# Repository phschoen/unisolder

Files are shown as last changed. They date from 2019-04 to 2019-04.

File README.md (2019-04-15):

# unisolder

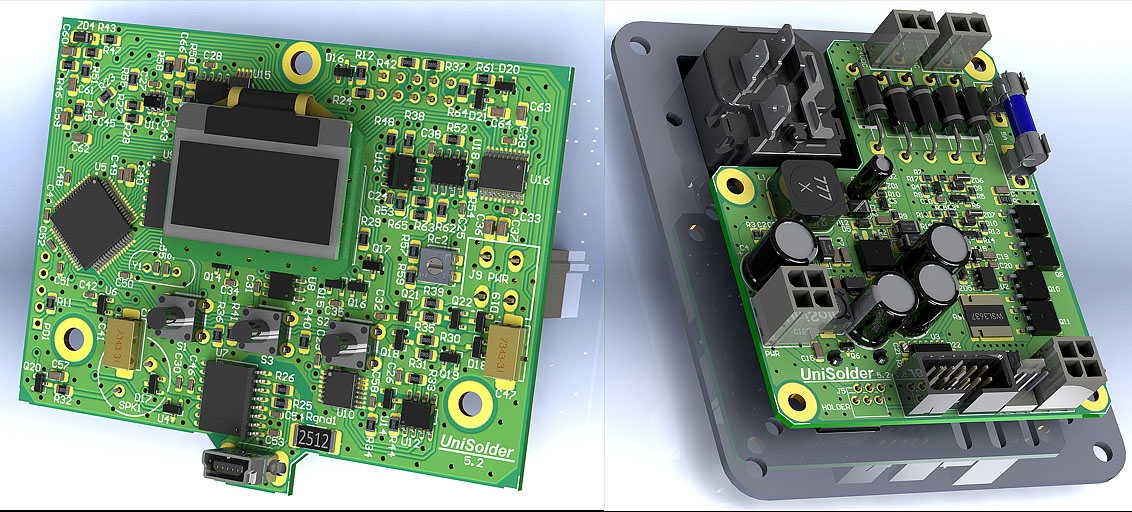
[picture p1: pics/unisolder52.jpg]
unisolder52


The intention was to build the most universal soldering controller I can think of.
It can drive any low voltage (upto 24V) iron with thermocouple or resistive sensor,
in series with the heater, or separate.

Here is a short list of features:
- power: 9-28V, AC or DC
- 2 separate heater control channels
- 2 independent sensor inputs
- current source on any sensor input 3uA - 12mA, wuth 2 bands (x1, x16) and 256 steps per band
- flexible differential amplifier input selection
- amplifier gain from 0 to 750 in 256 steps
- negative offset selection in 1024 steps
- resistive instrument identification (upto 625 different instruments can be identified by 2 resistors on the connector)
- polynomial floating point voltage/resistance to temperature calculation
- wave shaping to filter out the inductive peaks from series sensor signal
- PID control with power limit
- isolated USB port for firmware updates and live data
- 128x64 OLED display with rich user interface.

Tested so far with:
- HAKKO T12/T15 (series TC)
- HAKKO FX8801 (PTC)
- PACE TD100 (series TC)
- JBC C245 (series or separate TC)
- JBC C210 (series TC)
- JBC Microtweezers (2 separate heaters, each with series TC)
- WELLER WSP80 (PTC) (This iron was sent to me by a reader of the thread for a previous version of the controller. Thanks, Jaroslaw)
- ERSA RT80 (series PTC/heater resistance)
- various chinese cheap irons with separate TC

## Update (4 April 2017): 
The PC Software is now entirely in C#, the front end is rewritten. Now you can program only the bootloader,
and then use the software for firmware updates using the USB connection. The PC software also does not crash
anymore when device is unplugged and plugged in the USB or turned on/off, and automatically switches to
bootloader and back when uploading new firmware. Also, a legend with checkboxes is added for every data
that is displayed on the graph, so you can switch it on or off. There is still pretty much work to be done on it,
but at least it is much more functional now.
Added to the firmware are Pace TD100 Black and Weller WMRT profiles, some work is done on several other places.
Now the firmware handles better some irons, where there was initial overshoot when heating for the first time
or changing the target temperature.

Some movies:
 - [JBC C245](https://www.youtube.com/watch?v=oTdQB4ywDOA)
 - [JBC C210](https://www.youtube.com/watch?v=iyz-EDf-JaY)
 - [T12, JBC C210, JBC Microtweezers](https://www.youtube.com/watch?v=-f0KSU0PJzc&t=70s)
 - [Chinese T12](https://www.youtube.com/watch?v=u588sh-4thg)
 - [Weller WSP80](https://www.youtube.com/watch?v=gd_8w7l8_Bo)
 - [Weller WMRT](https://www.youtube.com/watch?v=eHNJuQEw6XU)

The content of this is originaly copied thanks to sparkybg from [dangerousprototypes.com](http://dangerousprototypes.com/forum/viewtopic.php?t=7218)

## Connections to different tips/irons:

1. HAKKO T12:
- Outer shell, and heater negative (middle) terminal connected together to Vout1- and EARTH
- heater positive (bottom terminal) connected to Vout1+ and SENSEA
- 1k resistor between ID and Vout1-
- 5.6k resistor between ID and Vout2-

2. HAKKO FX8801, HAKKO 907 (original, with PTC sensor):
- Outer shell, PTC negative and heater negative connected to EARTH, Vout1- and SENSEB
- Heater positive connected to Vout1+
- PTC positive connected to SENSEA
- 1k between ID and Vout1-
- 820ohm between ID and Vout2-

3. JBC C245:
- Outer shell (green wire) connected to EARTH and SENSEB
- Heater positive(red wire) connected to Vout1- and SENSEA
- Heater negative(blue wire) connected to Vout1+
- 150ohm between ID and Vout1-
- 5.6k between ID and Vout2-

4. JBC C210:
- Outer shell (green wire) connected to EARTH and SENSEB
- Heater negative (middle terminal, blue wire) connected to Vout1-
- Heater positive (smaller terminal, red wire) connected to Vout1+ and SENSEA
- 3.0k between ID and Vout1-
- 5.6k between ID and Vout2-

5. JBC Microtweezers:
- Outer shell of both tips (green wire) connected to EARTH
- Heater 1 negative (blue wire) connected to Vout1-
- Heater 1 positive (red wire) connected to Vout1+ and SENSEA
- Heater 2 negative (brown wire) connected to Vout2-
- Heater 2 positive (yellow wire) connected to Vout2+ and SENSEB
- 1.0k between ID and Vout1-

6. WELLER WSP80:
- Outer shell, PTC negative and heater negative (white, black and brown wires) connected to EARTH, Vout1- and SENSEB
- Heater positive (blue wire) connected to Vout1+
- PTC positive (red wire) connected to SENSEA
- 120ohm between ID and Vout1-
- 5.6k between ID and Vout2-

7. ERSA RT80:
- Outer shell and Heater/PTC negative (pink and white wires) connected to EARTH, Vout1- and SENSEB
- Heater/PTC positive (black wire) connected to Vout1+ and SENSEA
- 300ohm between ID and Vout1-
- 110ohm between ID and Vout2-

see also https://github.com/5N44P/unisolder-notes

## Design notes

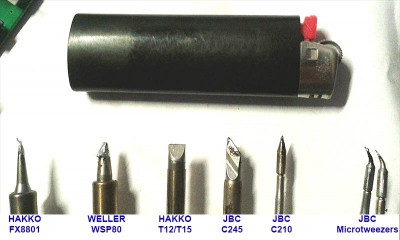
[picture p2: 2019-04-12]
pics/iron_tips.jpg

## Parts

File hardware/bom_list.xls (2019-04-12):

Designator | Comment | Supplier | Quantity | Package | Description
C1, C3, C5, C7, C9, C10, C17, C18, C59, C60, C62, C65 | 10n 100V | Comet | 12 | 0805 | Capacitor
C2, C6, C12, C16, C20, C21, C67, C70, C73, C74, C77 | 100n 100V | Comet | 11 | 0805 | Capacitor, Capacitor, Capacitor, Capacitor, Capacitor, Capacitor, Capacitor (Semiconductor SIM Model), Capacitor, Capacitor, Capacitor, Capacitor
C4 | 470uF 16V | Comet | 1 | TH10x12.5 | Polarized Capacitor (Radial)
C8, C11 | 220uF 50V | Comet | 2 | TH10x12.5 | Polarized Capacitor (Radial)
C13 | 22uF 50V | Comet | 1 | TH5x11 | Polarized Capacitor (Radial)
C14, C15, C19 | 10u 25V | Comet | 3 | 1206 | Capacitor
C22 | 47uF 100V | Comet | 1 | TH10x12.5 | Polarized Capacitor (Radial)
C23, C47 | 220uf 10V | Comet | 2 | D | Tantalum SMD Capacitor
C24, C25, C26, C27, C28, C29, C30, C31, C32, C33, C34, C35, C38, C39, C41, C42, C43, C44, C45, C46, C48, C49, C50, C51, C52, C53, C54, C58 | 100n | Comet | 28 | 0603 | Capacitor
C36, C37, C40, C57, C68, C69, C75 | 10u 16V | Comet | 7 | 0805 | Capacitor
C55, C56 | 15p | Comet | 2 | 0603 | Capacitor
C61, C63, C64, C66 | 1n | Comet | 4 | 0805 | Capacitor
C71 | 10u 25V | Comet | 1 | 0805 | Capacitor
C76 | 100p | Comet | 1 | 0805 | Capacitor
D1, D2, D3, D4 | SR580 | Comet | 4 | DO-201AD | Schottky Diode
D5, D8, D10, D14, D15 | BAT46WH | Comet | 5 | SOD123 | Schottky Rectifier
D6, D7, D12 | SS310A | Comet | 3 | SMA | Schottky Rectifier
D9, D11, D13 | 1N4007 | Comet | 3 | SMA | 1 Amp General Purpose Rectifier
D16, D17, D20, D21 | BAV199 | Farnell | 4 | SOT23
D18, D19 | MMBD1505A | Farnell | 2 | SOT23
D22 | SS34A | Comet | 1 | SMA | Schottky Rectifier
DS1, DS2, DS3 | SA36-11SRWA | Comet | 3 | DIP10 | 7.62 mm Black Surface HER 7-Segment Display: CA, RH DP
FUSE1 | 5A | Comet | 1 | 2x3518P | 2x Keystone 3518P fuse holder
J1 | 24VAC | Comet | 1 | 1x2x4.2 | Header, 2-Pin
J2 | IRON | Comet | 1 | 2x2x4.2 | Header, 4-Pin
J3, J9 | PWR | Comet | 2 | 2x2x4.2 | Header, 4-Pin
J4, J8 | CNTR | Comet | 2 | 2x5x2.54 | Header, 10-Pin
J5 | HOLDER | Comet | 1 | RJ11V | Header, 8-Pin
J6 | SENSOR | Comet | 1 | CI31-3 | Header, 3-Pin
J7 | 24VDC | Comet | 1 | 1x2x4.2 | Header, 2-Pin
Ja, Jb, Jc, Jd, Je, Jg | 0 | Comet | 6 | 0403 | Resistor
L1 | 330uH | Comet | 1 | DRH125 | Inductor
L2 | 330uH | Comet | 1 | DRH74 | Inductor
L3 | 10uH | Farnell | 1 | LPS4018 | Inductor
OLED1 | UG-2864HSWEG01 | Texim | 1 |  | 0.96' 128x64 OLED Display
P1, P2, PD1 | Header 5 | Comet | 3 | 1x5x2.54 | Header, 5-Pin
Q1 | FZT605 | Comet | 1 | SOT89 | SOT223 NPN Silicon Planar Medium Power Darlington Transistor
Q2, Q8 | SUD50P10 | Farnell | 2 | TO252 | HEXFET Power MOSFET
Q3, Q9 | MMBT5401 | Comet | 2 | SOT23 | PNP General-purpose Transistor
Q4, Q5, Q12 | MMBT5551 | Comet | 3 | SOT23 | NPN General-purpose Transistor
Q6, Q13 | BC847C | Comet | 2 | SOT23 | NPN General-purpose Transistor
Q7 | BCX56-16 | Comet | 1 | SOT89 | NPN High-voltage Transistor
Q10, Q11 | IPD053N08 | Farnell | 2 | TO252 | HEXFET N-Channel Power MOSFET
Q14, Q15, Q16, Q18, Q19, Q21, Q22 | IRLML6401 | Comet | 7 | SOT23 | HEXFET Power MOSFET
Q17, Q20 | IRLML2502 | Comet | 2 | SOT23 | HEXFET Power MOSFET
R1 | 10k | Comet | 1 | 1206 | Resistor
R2, R7, R15, R19, R21, R22 | 4.7k | Comet | 7 | 0805 | Resistor
R3 | 0 | Comet | 7 | 0805 | Resistor/Solder jumper
R4, R30, R35, R37, R42, R52, R54, R55, R56, R57, R59, R62, R65 | 1.5k 0.1% | Farnell, Farnell, Farnell, Farnell, Farnell, Farnell, Farnell, Comet, Farnell, Farnell, Farnell, Farnell, Farnell | 13 | 0805 | Resistor
R5, R11, R12, R13, R16, R17, R36, R40, R41, R45, R46, R58, R68, R69 | 3k | Comet | 14 | 0805 | Resistor
R6, R9, R14 | 150 | Comet | 3 | 0805 | Resistor
R8, R18 | 30k | Comet | 2 | 0805 | Resistor
R10 | 10k | Farnell | 1 | 0805 | Resistor
R20, R32 | 330 | Comet | 2 | 0805 | Resistor
R23, R27, R28, R33, R44 | 1.8k | Comet | 5 | 0805 | Resistor
R24, R34, R51, R60 | 1k 0.1% | Farnell | 4 | 0805 | Resistor
R25, R26 | 27 | Comet | 2 | 0805 | Resistor
R29, Ra, Rb, Rc, Rd, Re, Rf, Rg | 47 | Comet | 8 | 0805 | Resistor
R31, R39 | 100 0.1% | Farnell | 2 | 0805 | Resistor
R38, R48 | 47k 0.1% | Farnell | 2 | 0805 | Resistor
R43, R61, R64 | 15k | Comet | 3 | 0805 | Resistor
R47, R49, R50, R66 | 27k 0.1% | Farnell | 4 | 0805 | Resistor
R53, R63 | 10k 0.1% | Farnell | 2 | 0805 | Resistor
R67 | 820k | Comet | 1 | 0805 | Resistor
Rc2 | 2k | Farnell | 1 | Bourns 3362 | Potentiometer
Rgnd1 | 10000k | Comet | 1 | 2512 | Resistor
Rs1 | 0.003 | Comet | 1 | WSL3637 | 4lead shunt resistor
S1, S2, S3 | SWITCH-TACTILE | Comet | 3
SPK1 | PB1221P | Comet | 1 | SPK12x9x6.5 | Speaker 12mm
TVS1 | 60V | Farnell | 1 | DO-201AD | Tranzorb
U1 | LM2675M-3.3 | Comet | 1 | SOIC8 | SIMPLE SWITCHER® Power Converter High Efficiency 1A Step-Down Voltage Regulator, 8-pin Narrow SOIC
U2 | TC4428ACOA | Comet | 1 | SOIC8 | 1.5A Dual High-Speed Power MOSFET Driver, Complementary, Commercial Temperature
U3 | SN74HC02D | Comet | 1 | SOIC14 | Quadruple 2-Input Positive-NOR Gate
U4 | TC1047AVNBTR | Comet | 1 | SOT23 | Precision Temperature-to-Voltage Converter, 3-Pin SOT-23, Extended Temperature, Tape and Reel
U5 | PIC32MX564F128H-I/PT | Farnell | 1 | TQFP64 | High Performance 80 MHz MIPS-Based 32-Bit Flash Microcontroller with USB and CAN, 128KB Program Memory, 64-pin TQFP, Industrial Temperature
U6 | REF3030 | Farnell | 1 | SOT23
U7 | ADuM3160 | Farnell | 1 | SOIC16W | USB Isolator
U8 | 24LC64-I/SN | Comet | 1 | SOIC8 | 64Kbit, 400kHz, 2.5V, I2C Serial EEPROM, 8-Pin SOIC 150mil, Industrial Temperature
U9 | ULN2003L | Comet | 1 | SOIC16 | High-Voltage, High-Current Darlington Array
U10 | MCP4651-503E/ST | Farnell | 1 | TSSOP14 | 8-Bit Dual I2C Digital POT with Volatile Memory, 14-pin TSSOP, Extended Temperature
U11 | MCP4716A0T-E/CH | Farnell | 1 | SOT23-6 | 10-Bit Voltage Output Digital-to-Analog Converter with EEPROM and I2C Interface, 6-Pin SOT-23, Extended Temperature, Tape and Reel
U12, U13, U18 | MCP6V27-E/SN | Farnell | 3 | SOIC8 | 110 µA, High Precision Dual Op Amp, 8-Pin SOIC, Extended Temperature, 620 µA, 2 MHz Auto-Zeroed Dual Op Amp, 8-Pin SOIC, Extended Temperature, 620 µA, 2 MHz Auto-Zeroed Dual Op Amp, 8-Pin SOIC, Extended Temperature
U14 | LM4041CIM3-1.2 | Farnell | 1 | SOT23 | Precision Micropower Shunt Voltage Reference, 3-pin SOT-23
U15 | MCP4561T-503E/MS | Farnell | 1 | MSOP8 | 8-Bit Single I2C Digital POT with Non-Volatile Memory, 8-pin MSOP, Extended Temperature, Tape and Reel
U16 | ADG734 | Farnell | 1 | TSSOP20 | AD 4 SPDT
U17 | MCP6V28-E/SN | Farnell | 1 | SOIC8 | 620 µA, 2 MHz Auto-Zeroed Op Amp with CS pin, 8-Pin SOIC, Extended Temperature
U19 | FAN5331 | Comet | 1 | SOT23-5 | LED boost driver
USB1 | USB 5 pin | Comet | 1 | MINIUSB-V
Y1 | 8Mhz | Comet | 1 | HC49US | Crystal Oscillator
ZD1, ZD2 | 3V | Comet | 2 | SOD123 | Zener Diode
ZD3 | 36V | Comet | 1 | SOD123 | Zener Diode
ZD4 | 3.0V | Comet | 1 | SOD123 | Zener Diode
ZD5, ZD6, ZD7 | 15V | Comet | 3 | SOD123 | Zener Diode

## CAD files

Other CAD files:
software/front/US_BootLoader.X/l.obj
software/front/US_Firmware.X/l.obj
software/sensor/US_sensor.X/dist/default/production/US_sensor.X.production.obj
software/sensor/US_sensor.X/l.obj

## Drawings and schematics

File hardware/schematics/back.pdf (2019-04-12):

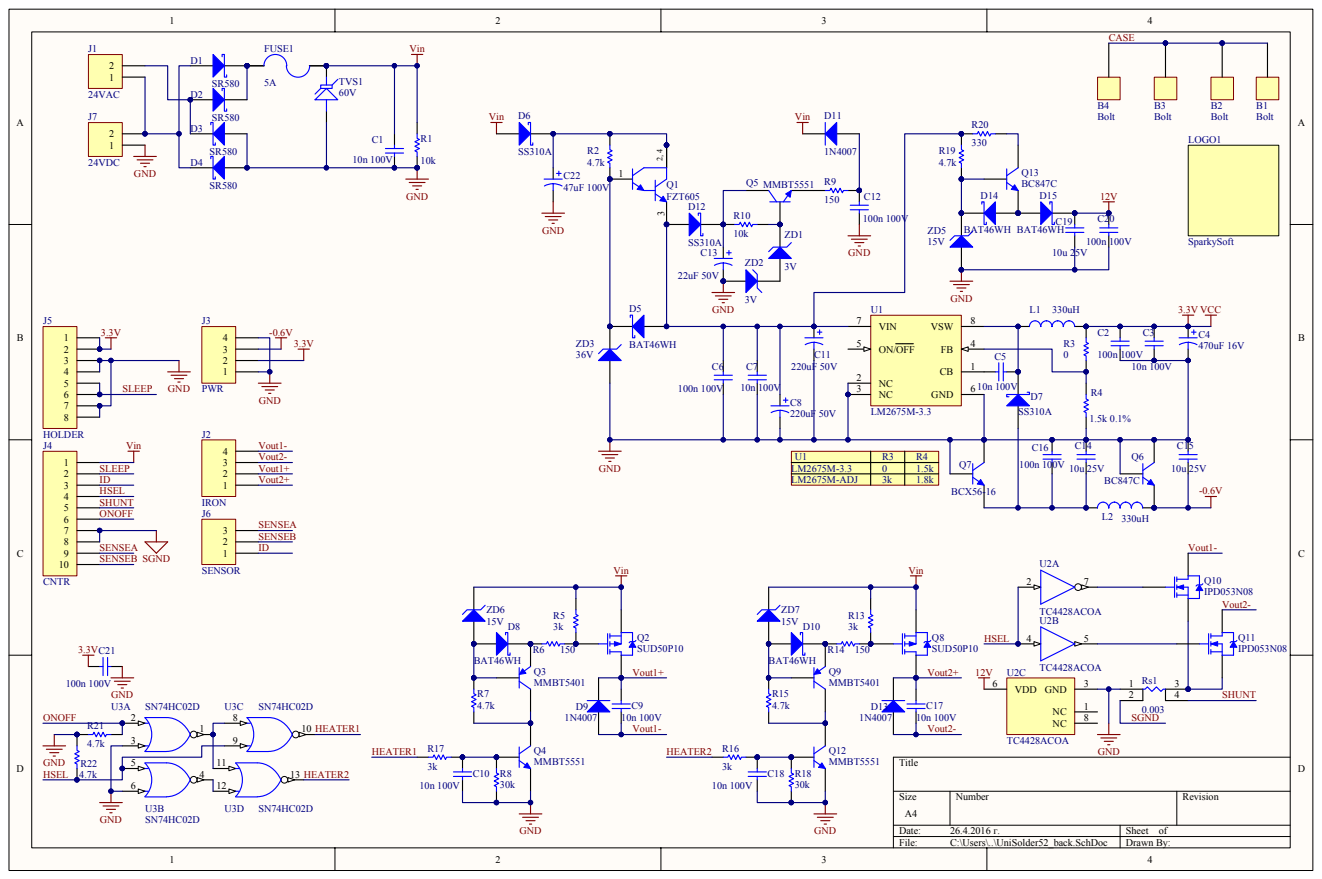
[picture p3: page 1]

Size A4 | Number | Revision

Date: 26.4.2016 г. | Sheet of
File: C:\Users\..\UniSolder52_back.SchDoc | Drawn By:

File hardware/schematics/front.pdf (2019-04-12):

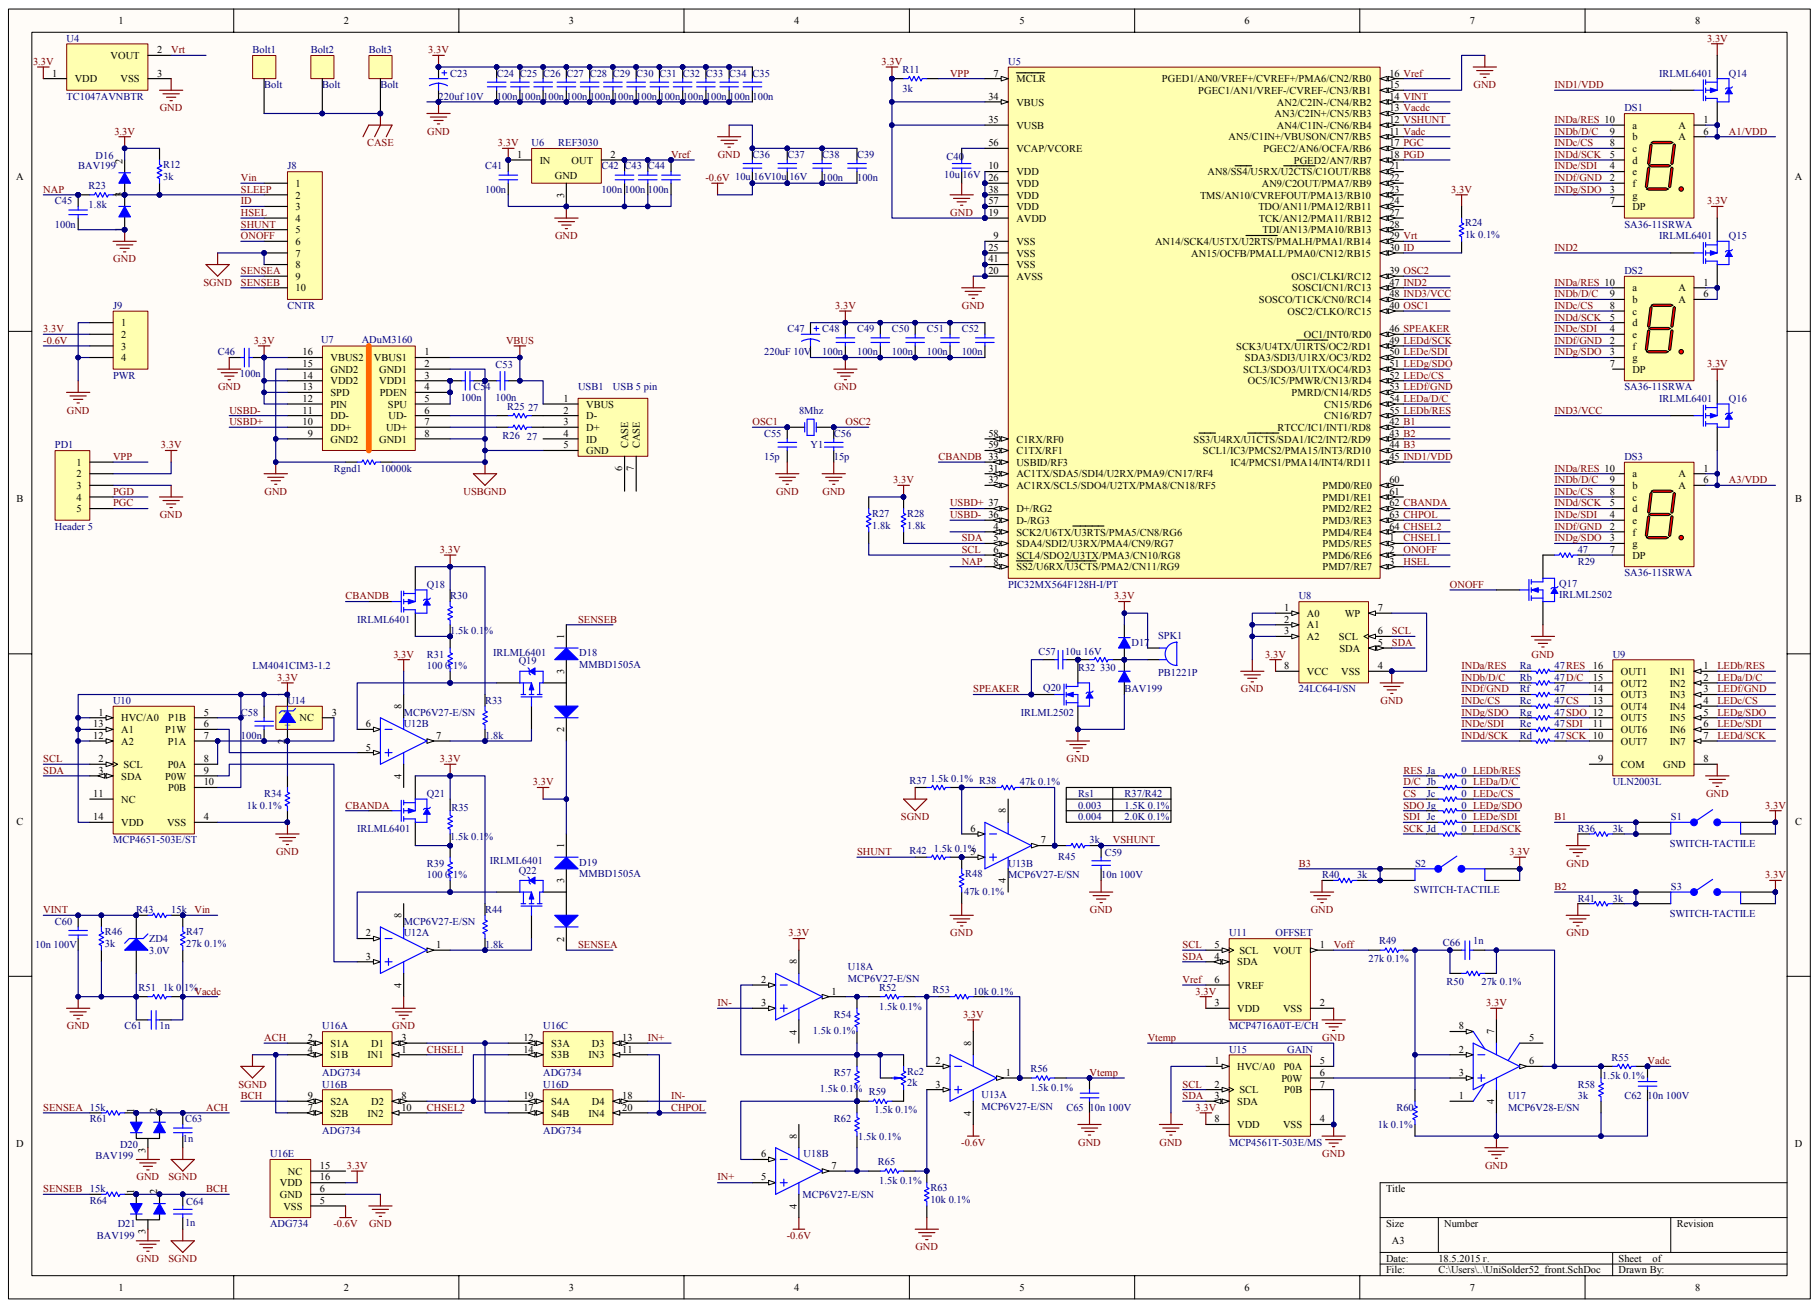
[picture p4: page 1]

Size A3 | Number | Revision

Date: 18.5.2015 г. | Sheet of
File: C:\Users\..\UniSolder52_front.SchDoc | Drawn By:

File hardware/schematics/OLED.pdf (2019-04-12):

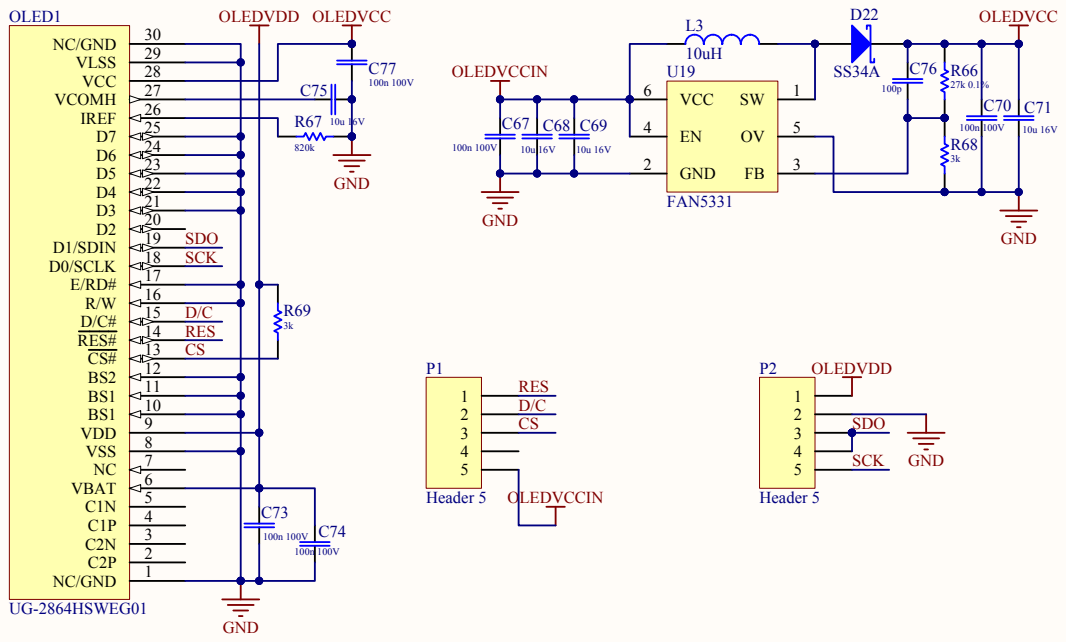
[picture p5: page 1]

Size A4 | Number | Revision

Date: 14.1.2015 г. | Sheet of
File: C:\Users\..\UniSolder52_OLED.SchDoc | Drawn By:

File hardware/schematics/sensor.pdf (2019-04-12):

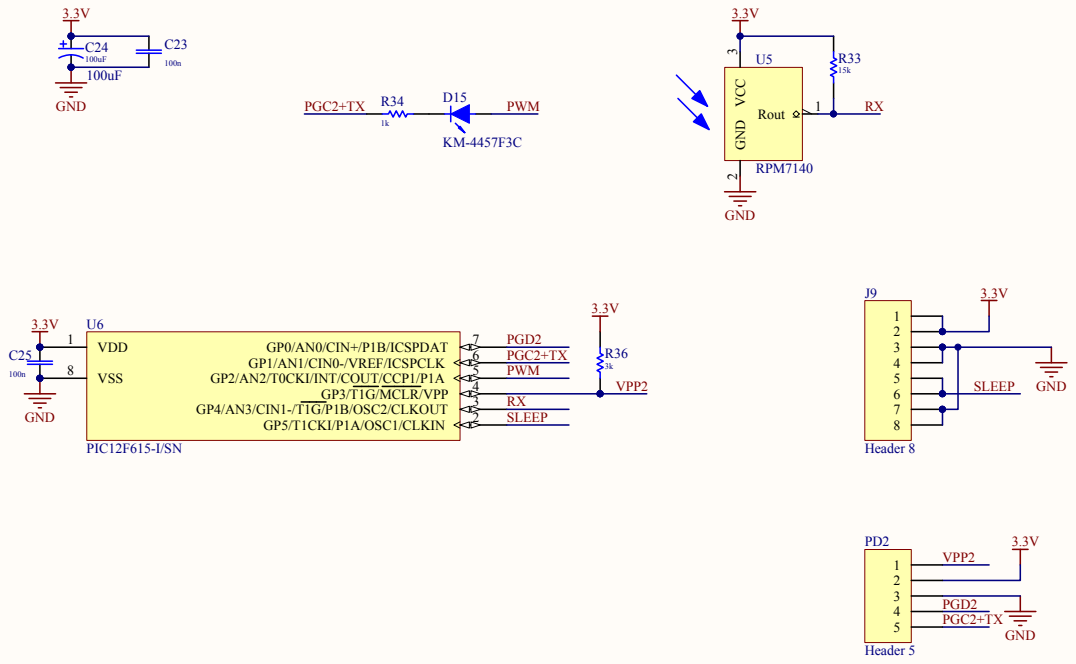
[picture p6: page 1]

Size A4 | Number | Revision

Date: 14.11.2014 г. | Sheet of
File: C:\Users\..\UniSolder_sensor.SchDoc | Drawn By:

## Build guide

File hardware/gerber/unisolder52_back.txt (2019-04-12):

%FSTAX23Y23*%
%MOIN*%
%SFA1B1*%

%IPPOS*%
%ADD9500C,0.028000*%
%ADD9501C,0.035430*%
%ADD9502C,0.043310*%
%ADD9503C,0.047240*%
%ADD9504C,0.055120*%
%ADD9505C,0.066930*%
%ADD9506C,0.068900*%
%ADD9507C,0.098430*%
%ADD9508C,0.125200*%
%ADD9509C,0.145670*%
%LNunisolder52_back-1*%
%LPD*%
G54D9500*
X04902Y0275D03*
X04907Y02878D03*
X05045Y02884D03*
X05068Y02992D03*
X04953Y02985D03*
X05179Y03025D03*
X05258Y03008D03*
X05243Y02905D03*
X05343Y02896D03*
X05351Y03053D03*
X05412Y03044D03*
X05472Y03053D03*
X05589Y03115D03*
X05551Y02896D03*
X05442Y02804D03*
X05232Y02757D03*
X05765Y02806D03*
X05767Y02898D03*
X06003Y02919D03*
X06073Y02757D03*
X05885Y0308D03*
X0453Y02906D03*
X04524Y02749D03*
X04303D03*
X04384Y0299D03*
X04186Y03181D03*
X04015Y03129D03*
X0404Y03314D03*
X04305Y03364D03*
X04515Y03337D03*
X04678Y0317D03*
X04572Y03785D03*
X0442Y0379D03*
X04317Y03767D03*
X0433Y03937D03*
X04321Y04078D03*
X04327Y04148D03*
X04223Y04134D03*
X04178Y04023D03*
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

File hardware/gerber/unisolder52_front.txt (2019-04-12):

%FSTAX23Y23*%
%MOIN*%
%SFA1B1*%

%IPPOS*%
%ADD9500C,0.027990*%
%ADD9501C,0.031500*%
%ADD9502C,0.035430*%
%ADD9503C,0.039370*%
%ADD9504C,0.055120*%
%ADD9505C,0.090550*%
%ADD9506C,0.137800*%
%LNunisolder52_front-1*%
%LPD*%
G54D9500*
X-00062Y-01451D03*
X0D03*
X00062D03*
X00031Y-01365D03*
X-00031D03*
X-01525Y-0116D03*
X-01421Y-01079D03*
X-01409Y-00976D03*
X-01484Y-00988D03*
X-015Y-00901D03*
X-01358Y-00717D03*
X-01359Y-00609D03*
X-01275Y-0057D03*
X-01094Y-00602D03*
X-01079Y-00733D03*
X-01027Y-00866D03*
X-01119Y-01014D03*
X-01075Y-01063D03*
X-01029Y-01119D03*
X-0121Y-01112D03*
X-01166Y-01237D03*
X-01421Y-01248D03*
X-00933Y-0124D03*
X-00704Y-01244D03*
X-00669Y-01146D03*
X-00736Y-01102D03*
X-00728Y-00831D03*
X-00759Y-00731D03*
X-00884Y-00803D03*
X-00887Y-00879D03*
X-01008Y-00997D03*
X-0097Y-00661D03*
X-00925Y-00563D03*
X-00869Y-00589D03*
X-00583Y-00621D03*
X-00508Y-00696D03*
X-00604Y-00797D03*
X-00639Y-00909D03*
X-00499Y-00926D03*
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

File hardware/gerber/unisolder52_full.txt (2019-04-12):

%FSTAX25Y25*%
%MOIN*%
%SFA1B1*%

%IPPOS*%
%ADD9500C,0.027990*%
%ADD9501C,0.031500*%
%ADD9502C,0.035430*%
%ADD9503C,0.039370*%
%ADD9504C,0.043310*%
%ADD9505C,0.047240*%
%ADD9506C,0.055120*%
%ADD9507C,0.066930*%
%ADD9508C,0.068900*%
%ADD9509C,0.090550*%
%ADD9510C,0.098430*%
%ADD9511C,0.125200*%
%ADD9512C,0.137800*%
%ADD9513C,0.145670*%
%LNunisolder52_full-1*%
%LPD*%
G54D9500*
X0136614Y0420866D03*
Y0427165D03*
Y0433465D03*
X0145276Y0430315D03*
Y0424016D03*
X0490256Y0275098D03*
X0490748Y0287894D03*
X0504528Y0288484D03*
X050689Y0299213D03*
X0495374Y0298524D03*
X0517913Y0302559D03*
X0525886Y0300886D03*
X0524311Y0290551D03*
X053435Y0289665D03*
X0535138Y0305315D03*
X054124Y0304429D03*
X0547244Y0305315D03*
X0558957Y0311516D03*
X0555118Y0289665D03*
X0544291Y0280413D03*
X0523228Y0275787D03*
X0576575Y028061D03*
X0576772Y0289862D03*
X0600394Y0291929D03*
X0607382Y0275787D03*
X0588583Y0308071D03*
X0453051Y029065D03*
X0452461Y0274902D03*
X0430315D03*
X04384Y0299095D03*
X0365256Y03D03*
X0364567Y0309449D03*
X0347091Y0312265D03*
X0343891Y0302165D03*
Y0296265D03*
X0345391Y0285465D03*
X0339491Y0286165D03*
X0332591Y0281465D03*
X0323591Y0291765D03*
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

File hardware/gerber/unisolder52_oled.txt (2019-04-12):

%FSTAX26Y26*%
%MOIN*%
%SFA1B1*%

%IPPOS*%
%ADD9500C,0.028000*%
%ADD9501C,0.035430*%
%LNunisolder52_oled-1*%
%LPD*%
G54D9500*
X-00486Y-00405D03*
X-00444Y-00323D03*
X-00448Y-00211D03*
X-0017815Y-0018996D03*
X-0002854Y-0018799D03*
X-0008465Y-00125D03*
X0004724Y-0013287D03*
X0018898Y-0010827D03*
X001811Y0002264D03*
X0033957Y0003248D03*
X0033268Y-0007185D03*
X0052067Y-0015354D03*
X00443Y-00262D03*
X0044488Y-0034843D03*
X0046544Y-00416D03*
X0026191Y-0041491D03*
X0016535Y-0041535D03*
X-0002756Y-0041634D03*
X-00177Y-00417D03*
X-00309Y-00416D03*
X-0032579Y0001969D03*
X-0026476Y-0000689D03*
X-00184Y0006D03*
X-001811Y0011909D03*
X-0017421Y0019882D03*
X-0004724Y0019783D03*
X-0001969Y0008169D03*
X000876Y0017618D03*
Y0030217D03*
X-0001969Y0036909D03*
X-00207Y0036D03*
X-00305Y00277D03*
X-0027657Y001565D03*
X-00503Y00211D03*
X-005Y00047D03*
X-00408Y00358D03*
X0022244Y0036909D03*
X00402Y00355D03*
X00508Y00213D03*
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

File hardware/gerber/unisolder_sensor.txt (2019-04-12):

%FSTAX26Y26*%
%MOIN*%
%SFA1B1*%

%IPPOS*%
%ADD9500C,0.028000*%
%ADD9501C,0.030000*%
%ADD9502C,0.035430*%
%ADD9503C,0.047240*%
%ADD9504C,0.125200*%
%ADD9505C,0.157480*%
%LNunisolder_sensor-1*%
%LPD*%
G54D9500*
X016Y0245D03*
X0164Y02569D03*
X0172Y02623D03*
X01851Y02622D03*
X0192Y02537D03*
X02Y0245D03*
X021Y0255D03*
X02233Y02685D03*
X021Y02828D03*
X02061Y02969D03*
X02246Y03065D03*
X02414Y03018D03*
X02625Y03022D03*
X0256Y02872D03*
X026Y0245D03*
X024D03*
X01969Y02726D03*
X01722Y02861D03*
X01626Y02957D03*
X01423Y0295D03*
X01247Y02949D03*
X0116Y02783D03*
X01015Y02805D03*
X00993Y02615D03*
X01105Y0266D03*
X01215Y02635D03*
X0129921Y0271654D03*
X0138Y027D03*
X014Y0245D03*
X012D03*
X01D03*
X01042Y03101D03*
X0155Y026D03*
X01183Y0313D03*
X0127Y03241D03*
X0105Y0335D03*
X02456Y03321D03*
X025Y032D03*
X02645Y03239D03*
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

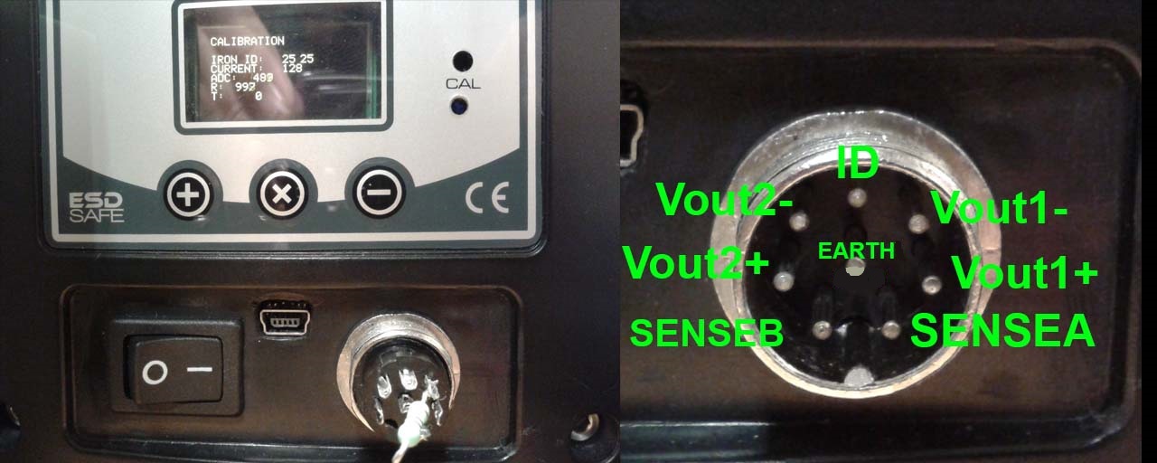
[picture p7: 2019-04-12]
pics/unisolder52_cal_con.jpg

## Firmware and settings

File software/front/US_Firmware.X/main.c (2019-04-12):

/* 
 * File:   main.c
 * Author: Sparky
 * Compiler: Microchip XC8 1.12
 *
 * Created on ??????, 2013, ?????? 5, 3:15
 */
#define _MAIN_C

#include "mcu.h"

#include <stddef.h>
#include <GenericTypeDefs.h>
#include <peripheral/int.h>
#include <peripheral/outcompare.h>
#include <peripheral/timer.h>
#include <peripheral/spi.h>
#include <peripheral/i2c.h>
#include <peripheral/cvref.h>
#include <peripheral/cmp.h>
#include <peripheral/adc10.h>
#include <peripheral/ports.h>
#include "typedefs.h"

#include "usb/usb.h"
#include "usb/usb_function_hid.h"

#include "main.h"

#include "isr.h"
#include "iron.h"
#include "PID.h"
#include "menu.h"
#include "io.h"
#include "EEP.h"
#include "OLED.h"
#include "pars.h"


volatile unsigned int   BeepTicks;
volatile unsigned int   InvertTicks;

volatile unsigned int   MAINS_PER;                  //mains voltage period
volatile unsigned int   T_PER;                      //ISR Timer period for mains frequency/1.2
volatile unsigned int   C_PER;                      //Character display period

volatile mainflags_t mainFlags = {1, 1, 1, 0};

/****** PARAMETERS SAVED IN EEPROM WHEN POWER IS LOST**************************/
volatile unsigned int   TTemp;                      //target temperature/2
volatile pars_t         pars;
/******************************************************************************/

void LoadPars(void)
{
    int i;
    UINT8 b,oldb;

    EEPRead(0, (UINT8 *)&pars, sizeof(pars));
    for(i = 0; i < sizeof(pars); i++){
        if((pars.b[i] < ParDef[i].Min) || (pars.b[i] > ParDef[i].Max)){
            for(i = 0; i < sizeof(pars); i++){
                pars.b[i] = ParDef[i].Default;
            }
            break;
        }
    }

    TTemp = 150;
    oldb=EEPRead(63 + 64, 0, 1);
    for(i = 0; i < 64; i++){
        b = EEPRead(i + 64, 0, 1);
        if((oldb == 0xFF) && (b >= 75) && (b <= 225)){
            TTemp = b;
            break;
        }
        oldb = b;
    }
}


void SavePars(void)
{
    int i;
    UINT8 b, oldb;

    for(i = 0; i < sizeof(pars); i++){
        if(EEPRead(i, 0 ,1) != pars.b[i])EEPWriteImm(i, pars.b[i]);
    }
    oldb = EEPRead(63 + 64, 0, 1);
    for(i = 0; i < 64; i++){
        b = EEPRead(i + 64, 0, 1);
        if((oldb==0xFF) && (b >= 75) && (b <= 225))break;
        oldb = b;
    }
    i &= 63;
    b=EEPRead(i + 64, 0, 1);
    if(b != TTemp){
        EEPWriteImm(i + 64, 0xFF);
        EEPWriteImm(((i + 1) & 63) + 64, TTemp);
    }
}


void main(void){
    int i;

    mcuInit1();

    OLED_CS=1;
    OLED_DC=1;
    OLED_RES=0;
    _delay_ms(100);
    SDI_OUT=0;
    SDO_OUT=0;
    SDISDO_OO;
    OLED_RES=1;
    mcuSPIOpen();
    OLEDInit();        
    OLEDPrintNum816(0, 0, 2, 0);
    OLEDUpdate();

    mcuInit2();

    SPEAKER=0;

    OLEDPrintNum816(0, 0, 2, 20);
    OLEDUpdate();
    OpenTimer1(T1_ON | T1_IDLE_STOP | T1_TMWDIS_OFF | T1_GATE_OFF | T1_PS_1_256 | T1_SYNC_EXT_OFF | T1_SOURCE_INT,0xFFFF);
    ConfigIntTimer1(T1_INT_OFF | T1_INT_PRIOR_7 | T1_INT_SUB_PRIOR_3);
    _delay_ms(100);
    OLEDPrintNum816(0, 0, 2, 21);
    OLEDUpdate();

    mainFlags.ACPower = 0;
    MAINS_PER = 0;
    mcuDCTimerReset();
    while(MAINS && (mT1GetIntFlag() == 0));
    _delay_us(100);
    while((!MAINS) && (mT1GetIntFlag() ==0));
    mcuDCTimerReset();
    for(i=0;((i<8) && (mT1GetIntFlag()==0));i++){
        _delay_us(100);
        while(MAINS && (mT1GetIntFlag()==0)){};
        _delay_us(100);
        while((!MAINS) && (mT1GetIntFlag()==0)){};
        MAINS_PER=ReadTimer1();
    }
    if(mT1GetIntFlag()){
        MAINS_PER=(PER_FREQ/256)/110;        //55Hz
        T_PER=MAINS_PER;
    }
    else{
        MAINS_PER>>=3;
        T_PER=MAINS_PER+((PER_FREQ/256)/1000);
        mainFlags.ACPower=1;
    }
    C_PER=(MAINS_PER-(PER_FREQ/256)/500)>>2;
    CloseTimer1();
    OpenTimer1(T1_ON | T1_IDLE_STOP | T1_TMWDIS_OFF | T1_GATE_OFF | T1_PS_1_256 | T1_SYNC_EXT_OFF | T1_SOURCE_INT, T_PER);
    OLEDPrintNum816(0, 0, 2, 22);
    OLEDUpdate();

    IronInit();
    OLEDPrintNum816(0, 0, 2, 31);
    OLEDUpdate();
    ISRInit();
    OLEDPrintNum816(0, 0, 2, 32);
    OLEDUpdate();
    PIDInit();
    OLEDPrintNum816(0, 0, 2, 33);
    OLEDUpdate();
    IOInit();
    OLEDPrintNum816(0, 0, 2, 34);
    OLEDUpdate();
    MenuInit();
    OLEDPrintNum816(0, 0, 2, 35);
    OLEDUpdate();

    if(mainFlags.ACPower){
        while(MAINS);
        while(!MAINS);
    }
    OLEDPrintNum816(0, 0, 2, 36);
    OLEDUpdate();
    
    mcuDCTimerReset();

    CMP2ConfigInt(CMP_INT_PRIOR_7 | CMP_INT_SUB_PRI_3 | CMP_INT_ENABLE);
    ConfigIntADC10(ADC_INT_PRI_7 | ADC_INT_SUB_PRI_3 | ADC_INT_ON);
    ConfigIntTimer1(T1_INT_ON | T1_INT_PRIOR_7 | T1_INT_SUB_PRIOR_3);
    OLEDPrintNum816(0, 0, 2, 41);
    OLEDUpdate();


    INTClearFlag(INT_I2C4B);
    INTClearFlag(INT_I2C4M);
    INTClearFlag(INT_I2C4S);
    INTClearFlag(INT_I2C4);
    INTSetVectorPriority(INT_I2C_4_VECTOR, INT_PRIORITY_LEVEL_6);
    INTSetVectorSubPriority(INT_I2C_4_VECTOR, INT_SUB_PRIORITY_LEVEL_3);
    INTEnable(INT_I2C4B,INT_ENABLED);
    INTEnable(INT_I2C4M,INT_ENABLED);
    INTEnable(INT_I2C4S,INT_ENABLED);
    INTEnable(INT_I2C4,INT_ENABLED);
    OLEDPrintNum816(0, 0, 2, 42);
    OLEDUpdate();

    INTClearFlag(INT_OC2);
    INTSetVectorPriority(_OUTPUT_COMPARE_2_VECTOR, INT_PRIORITY_LEVEL_5);
    INTSetVectorSubPriority(_OUTPUT_COMPARE_2_VECTOR, INT_SUB_PRIORITY_LEVEL_3);
    INTEnable(INT_OC2,INT_ENABLED);
    OLEDPrintNum816(0, 0, 2, 43);
    OLEDUpdate();

    mcuInitISRTimer();
    INTEnableSystemMultiVectoredInt();
    OLEDPrintNum816(0, 0, 2, 44);
    OLEDUpdate();

    CBANDA=1;
    CBANDB=1;
    CHSEL1=0;
    CHSEL2=1;
    CHPOL=0;
    I2CData.CurrentA.ui16=128;
    I2CData.CurrentB.ui16=128;
    I2CData.Gain.ui16=128;
    I2CData.Offset.ui16=128;
    I2CAddCommands(I2C_SET_CPOT | I2C_SET_GAINPOT | I2C_SET_OFFSET);
    OLEDPrintNum816(0, 0, 2, 45);
    OLEDUpdate();

    LoadPars();
    OLEDPrintNum816(0, 0, 2, 46);
    OLEDUpdate();

    ISRStop();
    OLEDPrintNum816(0, 0, 2, 47);    
    OLEDUpdate();

    mainFlags.PowerLost = 0;

    ISRStart();
    OLEDPrintNum816(0, 0, 2, 48);
    OLEDUpdate();

    while(1){
        if(mainFlags.PowerLost){
            SavePars();
            MenuTasks();
            _delay_ms(1000);
            mcuReset();
            while(1);
        }
        MenuTasks();
        IOTasks();
        IronTasks();
    }
}

#undef _MAIN_C
